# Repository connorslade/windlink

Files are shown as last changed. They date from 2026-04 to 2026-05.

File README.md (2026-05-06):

# windlink




System to show wind data on a Garmin watch for sailing.
Work in progress.

## References

- [The CANBoat project PGN documentation](https://canboat.github.io/canboat/canboat.html)

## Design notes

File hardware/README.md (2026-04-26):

# hardware

[View PCB / Schematic with KiCanvas](https://kicanvas.org/?repo=https%3A%2F%2Fgithub.com%2Fconnorslade%2Fwindlink%2Ftree%2Fmain%2Fhardware)

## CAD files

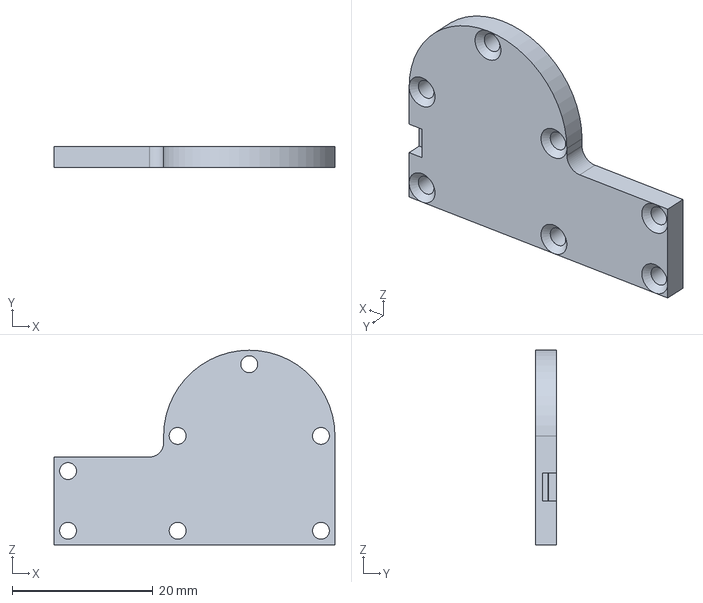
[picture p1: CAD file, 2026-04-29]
hardware/case.FCStd
40.0 x 3.00 x 27.7 mm

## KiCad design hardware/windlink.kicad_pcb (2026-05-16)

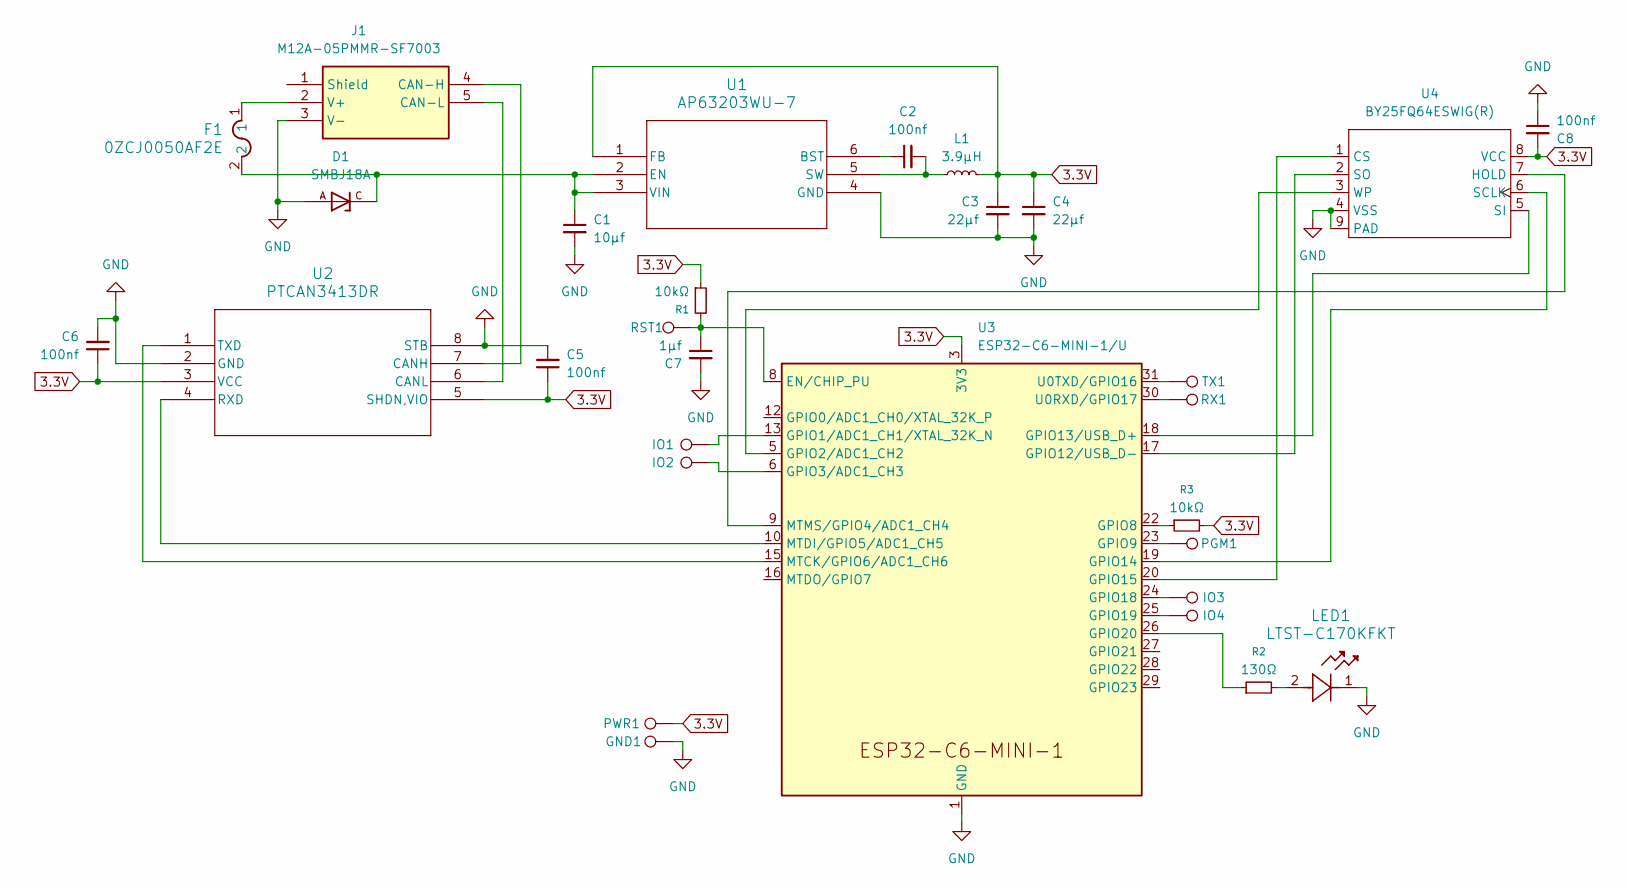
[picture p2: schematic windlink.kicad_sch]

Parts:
C1: 10μf; C_0805_2012Metric_Pad1.18x1.45mm_HandSolder
C2, C5, C6, C8: 100nf; C_0805_2012Metric_Pad1.18x1.45mm_HandSolder
C3, C4: 22μf; C_0805_2012Metric_Pad1.18x1.45mm_HandSolder
C7: 1μf; C_0805_2012Metric_Pad1.18x1.45mm_HandSolder
D1: SMBJ18A; DIOM4336X265N; PARTREV F2102
F1: 0ZCJ0050AF2E; 0ZCJ_BEL
GND1: TestPoint; TestPoint_Pad_D2.0mm
IO1, IO2, IO3, IO4: TestPoint; TestPoint_Pad_D2.0mm
J1: M12A-05PMMR-SF7003; M12A05PMMRSF7003; Manufacturer_Part_Number M12A-05PMMR-SF7003
L1: 3.9μH; IND_TAIYO_LBM2016_TAY
LED1: LTST-C170KFKT; LED_LTST-C170KFKT_LTO
PGM1: TestPoint; TestPoint_Pad_D2.0mm
PWR1: TestPoint; TestPoint_Pad_D2.0mm
R1, R3: 10kΩ; R_0805_2012Metric_Pad1.20x1.40mm_HandSolder
R2: 130Ω; R_0805_2012Metric_Pad1.20x1.40mm_HandSolder
RST1: TestPoint; TestPoint_Pad_D2.0mm
RX1: TestPoint; TestPoint_Pad_D2.0mm
TX1: TestPoint; TestPoint_Pad_D2.0mm
U1: AP63203WU-7; AP63203WU-7_DIO
U2: PTCAN3413DR; SOIC8_D_TEX
U3: ESP32-C6-MINI-1/U; ESP32-C6-MINI-1
U4: BY25FQ64ESWIG(R)

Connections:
3.3V: C3.1, C4.1, C5.1, C6.1, C8.2, L1.2, PWR1.1, R1.1, R3.2, U1.1 (FB), U2.3 (VCC), U2.5 (SHDN,VIO), U3.3 (3V3), U4.8 (VCC)
GND: C1.2, C3.2, C4.2, C5.2, C6.2, C7.2, C8.1, D1.A, GND1.1, J1.3 (V-), LED1.1, U1.4 (GND), U2.2 (GND), U2.8 (STB), U3.1 (GND), U3.2 (GND), U3.11 (GND), U3.14 (GND), U3.36 (GND), U3.37 (GND), U3.38 (GND), U3.39 (GND), U3.40 (GND), U3.41 (GND), U3.42 (GND), U3.43 (GND), U3.44 (GND), U3.45 (GND), U3.46 (GND), U3.47 (GND), U3.48 (GND), U3.49 (GND), U3.50 (GND), U3.51 (GND), U3.52 (GND), U3.53 (GND), U4.4 (VSS), U4.9 (PAD)
unnamed: F1.1, J1.2 (V+)
unnamed: LED1.2, R2.2
unnamed: C2.1, U1.6 (BST)
unnamed: C1.1, D1.C, F1.2, U1.2 (EN), U1.3 (VIN)
unnamed: C2.2, L1.1, U1.5 (SW)
unnamed: J1.4 (CAN-H), U2.7 (CANH)
unnamed: J1.5 (CAN-L), U2.6 (CANL)
unnamed: U2.4 (RXD), U3.10 (MTDI/GPIO5/ADC1_CH5)
unnamed: U2.1 (TXD), U3.15 (MTCK/GPIO6/ADC1_CH6)
unnamed: C7.1, R1.2, RST1.1, U3.8 (EN/CHIP_PU)
unnamed: IO1.1, U3.13 (GPIO1/ADC1_CH1/XTAL_32K_N)
unnamed: U3.5 (GPIO2/ADC1_CH2), U4.3 (WP)
unnamed: IO2.1, U3.6 (GPIO3/ADC1_CH3)
unnamed: R3.1, U3.22 (GPIO8)
unnamed: PGM1.1, U3.23 (GPIO9)
unnamed: U3.17 (GPIO12/USB_D-), U4.2 (SO)
unnamed: U3.18 (GPIO13/USB_D+), U4.5 (SI)
unnamed: U3.19 (GPIO14), U4.6 (SCLK)
unnamed: U3.20 (GPIO15), U4.1 (CS)
unnamed: IO3.1, U3.24 (GPIO18)
unnamed: IO4.1, U3.25 (GPIO19)
unnamed: R2.1, U3.26 (GPIO20)
unnamed: U3.9 (MTMS/GPIO4/ADC1_CH4), U4.7 (HOLD)
unnamed: RX1.1, U3.30 (U0RXD/GPIO17)
unnamed: TX1.1, U3.31 (U0TXD/GPIO16)

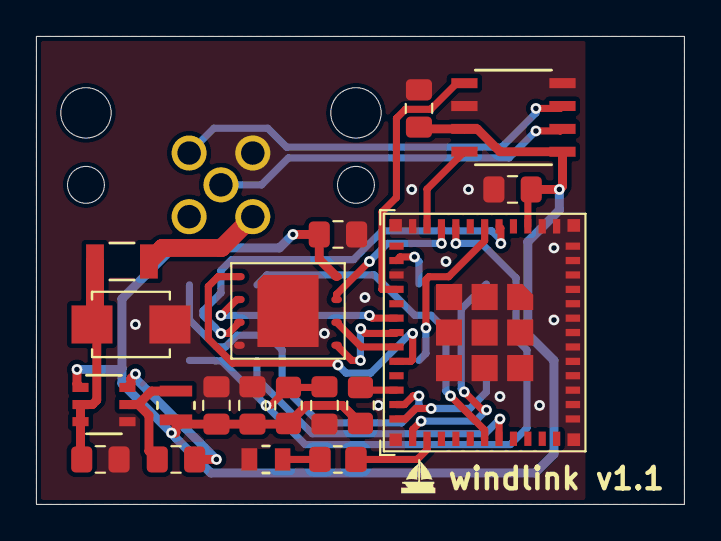
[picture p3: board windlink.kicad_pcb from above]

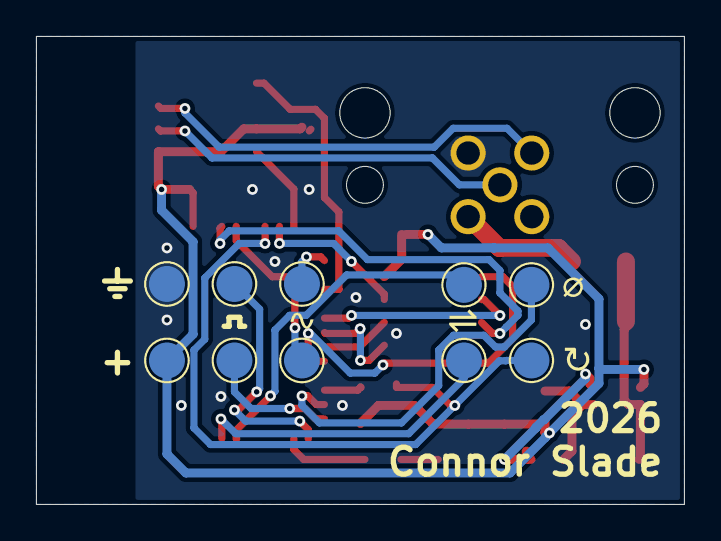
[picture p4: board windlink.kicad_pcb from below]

Board: 2 copper layers, 36.0 x 26.0 mm, 30 parts (10 on the bottom side), 27 nets.

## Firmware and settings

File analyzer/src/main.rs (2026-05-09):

use std::{
    io::{BufReader, BufWriter, Read, Write, stdin},
    net::{SocketAddr, TcpStream},
    sync::mpsc::sync_channel,
    thread,
};

use anyhow::{Result, bail};
use mdns_sd::{ServiceDaemon, ServiceEvent};
use nmea2000::{
    Header, Nmea2000,
    packets::{Packet, proprietary::SimnetAp},
};

fn main() -> Result<()> {
    println!("Searching for windlink");
    let service = find_service()?;
    println!("Found!");

    let socket = TcpStream::connect(service)?;
    let mut reader = BufReader::new(socket.try_clone()?);
    let mut writer = BufWriter::new(socket);

    let mut nmea2000 = Nmea2000::new();

    let (tx, rx) = sync_channel(10);
    thread::spawn(move || {
        loop {
            let out = &mut [0];
            if let Ok(1) = stdin().read(out)
                && out[0] == 10
            {
                tx.send(Packet::SimnetAp(SimnetAp {
                    address: 6,
                    proprietary: 255,
                    command: 10,
                    event: 6,
                }))
                .unwrap();
            }
        }
    });

    loop {
        let ident = u32::from_be_bytes(read_bytes::<4>(&mut reader)?);
        let header = Header::deserialize(ident);

        let mut data = [0_u8; 8];
        let length = read_bytes::<1>(&mut reader)?[0] as usize;
        reader.read_exact(&mut data[..length])?;

        if header.pgn == SimnetAp::PGN {
            println!(" | {header:?} {:?}", &data[..length]);
        }

        if let Some(Packet::SimnetAp(packet)) = nmea2000.on_packet(ident, data) {
            println!("{packet:?}");
        }

        while let Ok(packet) = rx.try_recv() {
            println!("enqueue!");
            nmea2000.enqueue(packet, 255);
        }
        for packet in nmea2000.dequeue() {
            println!("Sending {packet:?}");
            writer.write_all(&packet.id.to_be_bytes())?;
            writer.write_all(&[8])?;
            writer.write_all(&packet.data)?;
        }
    }
}

fn find_service() -> Result<SocketAddr> {
    let mdns = ServiceDaemon::new()?;
    let receiver = mdns.browse("_windlink._tcp.local.")?;

    while let Ok(event) = receiver.recv() {
        match event {
            ServiceEvent::ServiceResolved(service) => {
                let ip = service.addresses.iter().next().unwrap().to_ip_addr();
                return Ok(SocketAddr::new(ip, service.port));
            }
            _ => {}
        }
    }

    bail!("Couldn't find service")
}

fn read_bytes<const N: usize>(mut reader: impl Read) -> Result<[u8; N]> {
    let mut out = [0; N];
    reader.read_exact(&mut out)?;
    Ok(out)
}

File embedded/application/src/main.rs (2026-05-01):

#![feature(mapped_lock_guards)]
#![feature(iter_intersperse)]

use std::{sync::Arc, thread};

use anyhow::Result;
use esp_idf_hal::peripherals::Peripherals;

use crate::app::{App, MemoryLogger};

mod app;
mod ble;
mod can;
mod indicator;
mod util;
mod wifi;

fn main() -> Result<()> {
    esp_idf_svc::sys::link_patches();

    let peripherals = Peripherals::take()?;
    let (wifi_modem, _, ble_modem) = peripherals.modem.split();
    let pins = peripherals.pins;
    let ledc = peripherals.ledc;

    let app = Arc::new(App::new());
    let logger = Box::new(MemoryLogger { app: app.clone() });
    log::set_logger(Box::leak(logger))?;
    log::set_max_level(log::LevelFilter::Info);

    wifi::init(app.clone(), wifi_modem)?;
    ble::init(app.clone(), ble_modem)?;
    can::init(app.clone(), peripherals.can, pins.gpio4, pins.gpio5)?;
    indicator::init(app.clone(), ledc.channel0, ledc.timer0, pins.gpio14)?;

    loop {
        thread::park();
    }
}

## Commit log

2026-04-25 Add hardware files (PCB / Case)
    [case.FCStd, windlink.kicad_pcb, windlink.kicad_sch]
2026-04-25 Status LED
2026-04-26 Redesign case
    [case.FCStd]
2026-04-29 Rework case design
    [case.FCStd]
2026-04-30 WiFi OTA Updates
    [partitions.csv]
2026-04-30 Fix typo
    [partitions.csv]
2026-04-30 Move embedded modules into folder
    [partitions.csv]
2026-05-01 Wireless can interface
2026-05-03 Add frame destination
2026-05-11 PCB: Add extra flash and antenna cutout
    [windlink.kicad_pcb, windlink.kicad_sch]
2026-05-16 PCB: Finilize v1.1
    [windlink.kicad_pcb]
2026-05-16 PCB: Breakout jig
